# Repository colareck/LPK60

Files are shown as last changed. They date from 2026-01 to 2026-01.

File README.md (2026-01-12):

This is a 60% keyboard designed to use kailh choc switches. It has a full size 6.25u space bar.

keyboard-layout(1)

## Keyboard design

The keyboard is designed to use QMK firmware (still working on my commit for the QMK repo) with an STM32F072CBT6 microcontroller. The board should accept both v1 and v2 choc switches, it is importnat to note that with the current version the esc, tab, 1, and Q keys will need the plastic posts trimmed if using v1 switches. This was a design flaw that will be corrected in the next verison. MBK keycaps fit well, but I have not tested other keycaps. Currently, the only place I have sourced the 6.25u spacebar is from a custom order at fkcaps.com.

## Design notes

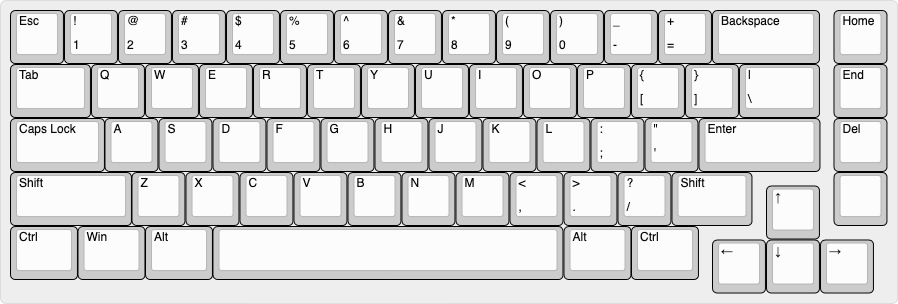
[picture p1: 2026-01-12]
keyboard-layout(1).png

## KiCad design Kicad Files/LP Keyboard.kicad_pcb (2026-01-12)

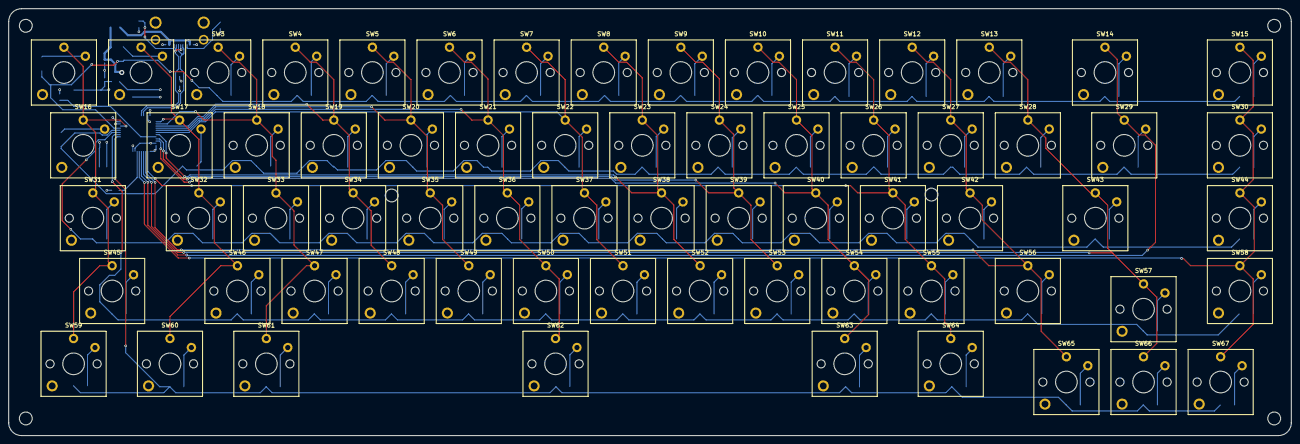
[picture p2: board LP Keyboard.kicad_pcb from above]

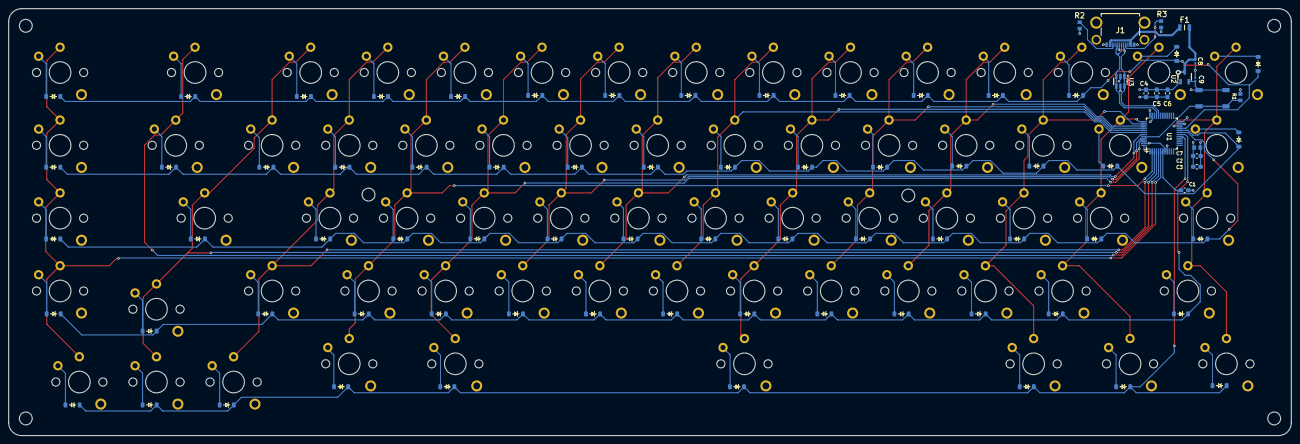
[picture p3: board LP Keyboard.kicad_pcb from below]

Board: 4 copper layers, 299.4 x 99.7 mm, 152 parts (85 on the bottom side), 97 nets.

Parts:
C1, C2, C3, C4, C5, C6: 100nF; C_0603_1608Metric_Pad1.08x0.95mm_HandSolder
C7: 10uF; 10uF Cap CAPC1608X100N
C8, C9: 1uF; 1uF lil CAPC0603X33N
D1, D2, D3, D4, D5, D6, D7, D8, D9, D10, D11, D12, D13, D14, D15, D16, D17, D18, D19, D20, D21, D22, D23, D24, D25, D26, D27, D28, D29, D30, D31, D32, D33, D34, D35, D36, D37, D38, D39, D40, D41, D42, D43, D44, D45, D46, D47, D48, D49, D50, D51, D52, D53, D54, D55, D56, D57, D58, D59, D60, D61, D62, D63, D64, D65, D66, D67: D_Small; Diode_SOD-123
F1: 500mA PPTC; FUSC2214X80N
J1: USB4500-03-0-A; USB4500030A
R1: 10k; RESC1608X50N
R2, R3: 5.1k; RESC1608X50N
SW1, SW2: SW_Push; Choc_V2_1.00u
SW3, SW4, SW5, SW6, SW7, SW8, SW9, SW10, SW11, SW12, SW13, SW15, SW18, SW19, SW20, SW21, SW22, SW23, SW24, SW25, SW26, SW27, SW28, SW30, SW32, SW33, SW34, SW35, SW36, SW37, SW38, SW39, SW40, SW41, SW42, SW44, SW46, SW47, SW48, SW49, SW50, SW51, SW52, SW53, SW54, SW55, SW57, SW58, SW65, SW66, SW67: SW_Push; Choc_V1V2_1.00u
SW14: SW_Push; Choc_V1V2_2.00u
SW16, SW17: SW_Push; Choc_V2_1.50u
SW29, SW56, SW64: SW_Push; Choc_V1V2_1.50u
SW31: SW_Push; Choc_V1V2_1.75u
SW43, SW45: SW_Push; Choc_V1V2_2.25u
SW59, SW60, SW61, SW63: SW_Push; Choc_V1V2_1.25u
SW62: SW_Push; Choc_V1V2_6.25u
SW68: Boot Button; Button_TL3342
U1: STM32F072CBT6; LQFP-48_7x7mm_P0.5mm
U2: XC6206P332MR-G; SOT-23-3
U3: USBLC6-2SC6; SOT-23-6

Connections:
+3V3: C2.1, C3.1, C4.1, C5.1, C6.1, C7.1, C9.1, SW68.2, U1.1 (VBAT), U1.9 (VDDA), U1.24 (VDD), U1.36 (VDDIO2), U1.48 (VDD), U2.2 (VO)
+5V: C8.1, F1.2, U2.3 (VI), U3.5 (VBUS)
D+: J1.A6 (DP1), J1.B6 (DP2), U1.33 (PA12), U3.3 (I/O2), U3.4 (I/O2)
D-: J1.A7 (DN1), J1.B7 (DN2), U1.32 (PA11), U3.1 (I/O1), U3.6 (I/O1)
GND: C1.2, C2.2, C3.2, C4.2, C5.2, C6.2, C7.2, C8.2, C9.2, J1.A1 (GND_1), J1.A12 (GND_2), R1.2, R2.2, R3.1, U1.8 (VSSA), U1.23 (VSS), U1.35 (VSS), U1.47 (VSS), U2.1 (GND), U3.2 (GND)
unnamed: D1.2 (A), SW1.2
unnamed: D2.2 (A), SW2.2
unnamed: D3.2 (A), SW3.2
unnamed: D4.2 (A), SW4.2
unnamed: D5.2 (A), SW5.2
unnamed: D6.2 (A), SW6.2
unnamed: D7.2 (A), SW7.2
unnamed: D8.2 (A), SW8.2
unnamed: D9.2 (A), SW9.2
unnamed: D10.2 (A), SW10.2
unnamed: D11.2 (A), SW11.2
unnamed: D12.2 (A), SW12.2
unnamed: D13.2 (A), SW13.2
unnamed: D14.2 (A), SW14.2
unnamed: D15.2 (A), SW15.2
unnamed: D16.2 (A), SW16.2
unnamed: D17.2 (A), SW17.2
unnamed: D18.2 (A), SW18.2
unnamed: D19.2 (A), SW19.2
unnamed: D20.2 (A), SW20.2
unnamed: D21.2 (A), SW21.2
unnamed: D22.2 (A), SW22.2
unnamed: D23.2 (A), SW23.2
unnamed: D24.2 (A), SW24.2
unnamed: D25.2 (A), SW25.2
unnamed: D26.2 (A), SW26.2
unnamed: D27.2 (A), SW27.2
unnamed: D28.2 (A), SW28.2
unnamed: D29.2 (A), SW29.2
unnamed: D30.2 (A), SW30.2
unnamed: D31.2 (A), SW31.2
unnamed: D32.2 (A), SW32.2
unnamed: D33.2 (A), SW33.2
unnamed: D34.2 (A), SW34.2
unnamed: D35.2 (A), SW35.2
unnamed: D36.2 (A), SW36.2
unnamed: D37.2 (A), SW37.2
unnamed: D38.2 (A), SW38.2
unnamed: D39.2 (A), SW39.2
unnamed: D40.2 (A), SW40.2
unnamed: D41.2 (A), SW41.2
unnamed: D42.2 (A), SW42.2
unnamed: D43.2 (A), SW43.2
unnamed: D44.2 (A), SW44.2
unnamed: D45.2 (A), SW45.2
unnamed: D46.2 (A), SW46.2
unnamed: D47.2 (A), SW47.2
unnamed: D48.2 (A), SW48.2
unnamed: D49.2 (A), SW49.2
unnamed: D50.2 (A), SW50.2
unnamed: D51.2 (A), SW51.2
unnamed: D52.2 (A), SW52.2
unnamed: D53.2 (A), SW53.2
unnamed: D54.2 (A), SW54.2
unnamed: D55.2 (A), SW55.2
unnamed: D56.2 (A), SW56.2
unnamed: D57.2 (A), SW57.2
unnamed: D58.2 (A), SW58.2
unnamed: D59.2 (A), SW59.2
unnamed: D60.2 (A), SW60.2
unnamed: D61.2 (A), SW61.2
unnamed: D62.2 (A), SW62.2
unnamed: D63.2 (A), SW63.2
unnamed: D64.2 (A), SW64.2
unnamed: D65.2 (A), SW65.2
unnamed: D66.2 (A), SW66.2
unnamed: D67.2 (A), SW67.2
unnamed: J1.A5 (CC1), R3.2
unnamed: J1.B5 (CC2), R2.1
unnamed: R1.1, SW68.1, U1.44 (BOOT0)
unnamed: C1.1, U1.7 (NRST)
VBUS: F1.1, J1.A4 (VBUS_1), J1.A9 (VBUS_2)
col 0: SW1.1, SW16.1, SW31.1, SW45.1, SW59.1, U1.22 (PB11)
col 1: SW2.1, SW17.1, SW32.1, SW46.1, SW60.1, U1.37 (PA14)
col 2: SW3.1, SW18.1, SW33.1, SW47.1, SW61.1, U1.38 (PA15)
col 3: SW4.1, SW19.1, SW34.1, SW48.1, U1.39 (PB3)
col 4: SW5.1, SW20.1, SW35.1, SW49.1, U1.40 (PB4)
col 5: SW6.1, SW21.1, SW36.1, SW50.1, SW62.1, U1.41 (PB5)
col 6: SW7.1, SW22.1, SW37.1, SW51.1, U1.42 (PB6)
col 7: SW8.1, SW23.1, SW38.1, SW52.1, U1.43 (PB7)
col 8: SW9.1, SW24.1, SW39.1, SW53.1, U1.45 (PB8)
col 9: SW10.1, SW25.1, SW40.1, SW54.1, SW63.1, U1.46 (PB9)
col 10: SW11.1, SW26.1, SW41.1, SW55.1, SW64.1, U1.2 (PC13)
col 11: SW12.1, SW27.1, SW42.1, SW56.1, SW65.1, U1.3 (PC14)
col 12: SW13.1, SW28.1, SW43.1, SW57.1, SW66.1, U1.4 (PC15)
col 13: SW14.1, SW29.1, U1.5 (PF0)
col 14: SW15.1, SW30.1, SW44.1, SW58.1, SW67.1, U1.6 (PF1)
row 0: D1.1 (K), D2.1 (K), D3.1 (K), D4.1 (K), D5.1 (K), D6.1 (K), D7.1 (K), D8.1 (K), D9.1 (K), D10.1 (K), D11.1 (K), D12.1 (K), D13.1 (K), D14.1 (K), D15.1 (K), U1.21 (PB10)
row 1: D16.1 (K), D17.1 (K), D18.1 (K), D19.1 (K), D20.1 (K), D21.1 (K), D22.1 (K), D23.1 (K), D24.1 (K), D25.1 (K), D26.1 (K), D27.1 (K), D28.1 (K), D29.1 (K), D30.1 (K), U1.20 (PB2)
row 2: D31.1 (K), D32.1 (K), D33.1 (K), D34.1 (K), D35.1 (K), D36.1 (K), D37.1 (K), D38.1 (K), D39.1 (K), D40.1 (K), D41.1 (K), D42.1 (K), D43.1 (K), D44.1 (K), U1.19 (PB1)
row 3: D45.1 (K), D46.1 (K), D47.1 (K), D48.1 (K), D49.1 (K), D50.1 (K), D51.1 (K), D52.1 (K), D53.1 (K), D54.1 (K), D55.1 (K), D56.1 (K), D57.1 (K), D58.1 (K), U1.18 (PB0)
row 4: D59.1 (K), D60.1 (K), D61.1 (K), D62.1 (K), D63.1 (K), D64.1 (K), D65.1 (K), D66.1 (K), D67.1 (K), U1.17 (PA7)

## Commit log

2026-01-12 Added design files
    Added KLE json and png outputs. Added plate svg generated by plate.keeb.io.
2026-01-12 Create Kicad folder
2026-01-13 Corrected switch plate SVG
2026-01-13 Delete kbplate(3).svg
    old switch plate svg, doesn't work
